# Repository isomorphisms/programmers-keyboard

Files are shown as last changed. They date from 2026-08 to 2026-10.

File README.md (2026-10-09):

# Programmer’s Keyboard

A modular keyboard project built around dedicated keypads for programming, mathematics, navigation, and command-heavy work.

The repository contains generated keypad layouts and the first routed hardware segment. It is experimental hardware, not a finished keyboard product.

## Key groups

- cursor and page movement
- process and system signals
- mathematical symbols such as `÷`, `≤`, `×`, `=`, `−`, and `⇒`
- programming symbols and operations
- regular-expression anchors and quantifiers
- concept separation and naming
- command-history search and completion
- several visible paste buffers

Layout previews are in [`pictures of the keypads`](pictures%20of%20the%20keypads). [`render-keypads`](render-keypads) generates them from ordinary Idris 2: Idris writes SVG layouts, then standard Debian tools produce PNG previews and raw PGM copies.

## Movement keypad prototype

The first routed segment is a 132 mm × 70 mm USB-C/RP2040 board with:

- twelve hot-swap key positions
- twelve diodes
- a 3×4 key matrix
- four mounting holes

Files:

- [Gerber ZIP](fabrication/movement-prototype-gerbers.zip)
- [Gerber, drill, BOM, and placement files](fabrication/movement-prototype-gerbers)
- [PCB preview](fabrication/movement-prototype-pcb.svg)
- [schematic preview](fabrication/movement-prototype-schematic.svg)
- [readable netlist](fabrication/movement-prototype-readable.netlist)
- [tscircuit source](pcb/movement-prototype.tsx)
- [source and validation notes](pcb)

Routed Movement keypad prototype

## Status

This board is a routing prototype. It has not been declared ready to order. Switch mechanics, USB protection, enclosure clearances, firmware, component availability, and final electrical review remain open.

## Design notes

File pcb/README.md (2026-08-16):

# Movement keypad PCB prototype

This is the first deliberately small electrical segment of the programmers' keyboard. It is not the complete keyboard.

The board contains:

- one complete RP2040 support circuit;
- one USB-C connector for USB data and power;
- twelve Kailh-style hot-swap key positions;
- twelve matrix diodes;
- a 3-row by 4-column key matrix; and
- four non-plated mounting holes.

The key faces use semantic operations rather than Vim letters:

| Row | Keys |
| --- | --- |
| 1 | Movement, Type, Previous Line, Next Line |
| 2 | Start Line, End Line, Next Word, Next Space-Separated Word |
| 3 | 7 Times, 13 Times, Delete Character, Delete Word |

The controller maps GPIO0–GPIO2 to the rows and GPIO3–GPIO6 to the columns. The rectangular board is 132 mm by 70 mm. Placement is explicit; tscircuit's local autorouter handles the copper.

## Generate the fabrication package

From this directory:

```sh
npm ci
npm run typecheck
npx tsci export movement-prototype.tsx --format circuit-json \
  --output ../fabrication/movement-prototype.circuit.json
npx tsci export movement-prototype.tsx --format pcb-svg \
  --output ../fabrication/movement-prototype-pcb.svg
npx tsci export movement-prototype.tsx --format schematic-svg \
  --output ../fabrication/movement-prototype-schematic.svg
npx tsci export movement-prototype.tsx --format readable-netlist \
  --output ../fabrication/movement-prototype-readable.netlist
npx tsci export movement-prototype.tsx --format gerbers \
  --output ../fabrication/movement-prototype-gerbers.zip
```

Extract the ZIP before validating:

```sh
rm -rf ../fabrication/movement-prototype-gerbers
mkdir -p ../fabrication/movement-prototype-gerbers
unzip -q ../fabrication/movement-prototype-gerbers.zip \
  -d ../fabrication/movement-prototype-gerbers
node scripts/validate-output.mjs
```

The GitHub workflow repeats this process and checks that the committed Gerber layers, drills, previews, netlist, and Circuit JSON reproduce from the source. The validator rejects circuit error elements, missing keys or diodes, missing RP2040/USB-C parts, too few routed traces, missing Gerber layers, and missing or implausibly small drill files.

The currently checked-in run reports 63 components, 146 source traces, 125 routed PCB traces, 10 Gerber layers, and 2 drill files.

This is a routing prototype, not yet a production release. Switch choice, key spacing, board outline, ESD protection, firmware, component availability, and mechanical enclosure still need human review before ordering boards.

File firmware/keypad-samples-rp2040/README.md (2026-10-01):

# RP2040 samples for the remaining keypad layouts

This directory extends the existing RP2040/TinyUSB pattern without claiming that the remaining keypad PCBs have been routed. It builds one UF2 per currently unimplemented layout:

- Concept Separation
- Incantation Assistance
- Math
- Regular Expressions
- Several Pastebins
- Signals

The routed Movement board remains in `firmware/movement-rp2040`. The Programming `λ` proof remains on the separate `firmware/programming-lambda` branch; this directory does not replace either of them.

## Hardware assumption for these samples

The remaining layouts do not yet have checked-in PCB wiring, and the current Regex meaning list needs thirteen distinct actions. The sample therefore assumes one common diode-isolated 4×4 switch matrix:

- rows: GPIO0, GPIO1, GPIO2, GPIO3
- columns: GPIO4, GPIO5, GPIO6, GPIO7
- columns use RP2040 internal pull-ups
- one row at a time is driven low; inactive rows float
- each switch is wired from its column to the diode anode, with the diode cathode connected to its row, matching the routed Movement matrix direction
- a closed switch reads low on its column
- five consecutive 1 ms samples are required before a state change is accepted

This is **not** the routed Movement prototype pinout. Movement is 3×4 with rows GPIO0–GPIO2 and columns GPIO3–GPIO6. These UF2s are samples for breadboarding or later PCB work; do not flash one onto the Movement board and assume its physical key positions match.

All tables below use row-major matrix positions: position 0 is row 0/column 0, position 1 is row 0/column 1, position 4 is row 1/column 0, and so on. Unlisted positions do nothing. Where `Renderer.idr` already defines rows, the sample leaves unused column 3 positions empty so those rows remain recognizable inside the common 4×4 matrix.

## Concept Separation

The existing rendered rows are 4 + 2, which fit directly in the common matrix.

| Position | Current meaning | Sample host encoding |
| ---: | --- | --- |
| 0 | QUAD SPACE | U+2001 EM QUAD via Linux `Ctrl+Shift+U 2001 Enter` |
| 1 | FOUR SPACES | four ASCII spaces |
| 2 | DOUBLE SPACE | two ASCII spaces |
| 3 | SINGLE SPACE | one ASCII space |
| 4 | INDENT | `Tab` |
| 5 | UNDERSCORE | `_` |

`QUAD SPACE` is kept as a distinct semantic action from `FOUR SPACES`; this sample interprets the former as the Unicode EM QUAD rather than silently making the two keys identical.

## Incantation Assistance

The existing rendered layout is one row of three keys.

| Position | Current meaning | HID output |
| ---: | --- | --- |
| 0 | TAB / COMPLETE | `Tab` |
| 1 | FINISH INCANTATION | `Enter` |
| 2 | CHANT HISTORY | `Ctrl-R` |

## Math

The rendered Math layout has two rows of four faces plus a third-row `⇒` face. The text source gives the two comparison faces paired meanings, `< / ≤` and `> / ≥`. To preserve both meanings without inventing a tap/hold convention, the sample assumes each of those two faces is a two-contact rocker. The extra contacts occupy otherwise-unused matrix positions 10 and 11; their matrix coordinates are wiring choices, not extra visible key faces.

For a concrete SPDT implementation, the `< / ≤` rocker can put its common on column 2, with one throw going through a diode to row 1 (position 6) and the other through a diode to row 2 (position 10). The `> / ≥` rocker can do the same on column 3 for positions 7 and 11. Two electrically independent normally-open contacts are equivalent. In either case the diode anode is on the contact/column side and the cathode is on the row side.

Unicode operators use the same Linux Unicode-input approach as the existing Programming `λ` proof.

| Position | Current meaning | Sample host encoding |
| ---: | --- | --- |
| 0 | ADD | `+` |
| 1 | SUBTRACT | U+2212 `−` |
| 2 | MULTIPLY | U+00D7 `×` |
| 3 | DIVIDE | U+00F7 `÷` |
| 4 | EQUAL | `=` |
| 5 | NOT EQUAL | U+2260 `≠` |
| 6 | `<` contact of `< / ≤` | `<` |
| 10 | `≤` contact of `< / ≤` | U+2264 `≤` |
| 7 | `>` contact of `> / ≥` | `>` |
| 8 | FAT ARROW | U+21D2 `⇒` |
| 11 | `≥` contact of `> / ≥` | U+2265 `≥` |

A final PCB can choose different matrix coordinates for the second rocker contacts without changing the semantic actions or encodings.

## Regular Expressions

The text definition, `Renderer.idr`, and the firmware now use the same thirteen meanings in the same row-major 4 + 4 + 4 + 1 arrangement. The firmware build checks that agreement before compiling the UF2, so changing any one of those three representations without updating the others fails CI.

This encoder targets PCRE2/Perl-like syntax on a US keyboard layout. The semantic names stay separate from that dialect choice.

| Position | Current meaning | Sample text |
| ---: | --- | --- |
| 0 | START OF LINE | `^` |
| 1 | END OF LINE | `$` |
| 2 | END OF SLURP | `\z` |
| 3 | maybe (ok if not?) | `?` |
| 4 | big capture (greedy) | `(.*)` |
| 5 | small capture (non greedy) | `(.*?)` |
| 6 | group of characters in exactly this order | `()` |
| 7 | any character from this list | `[]` |
| 8 | letter | `\p{L}` |
| 9 | number | `\d` |
| 10 | non weird character | `\w` |
| 11 | weird character | `\W` |
| 12 | incantation runes / control characters | `\p{Cc}` |

If another regex dialect is desired, change only these text encodings; the semantic names do not need to change.

## Several Pastebins

The existing rendered layout is 3×3. Column 3 of each sample matrix row is therefore unused.

The repository defines pastebin operations but not a universal host shortcut or daemon. Guessing clipboard shortcuts would change the meaning. The sample therefore emits otherwise-unused extended function-key usages for a host binding layer:

| Position | Current meaning | HID transport token |
| ---: | --- | --- |
| 0 | VIEW₁ | `F13` |
| 1 | VIEW₂ | `F14` |
| 2 | VIEW₃ | `F15` |
| 4 | REMEMBER₁ | `F16` |
| 5 | REMEMBER₂ | `F17` |
| 6 | REMEMBER₃ | `F18` |
| 8 | WRITE₁ | `F19` |
| 9 | WRITE₂ | `F20` |
| 10 | WRITE₃ | `F21` |

A host binding can then implement the actual three pastebins without changing firmware key identity.

## Signals

The existing rendered layout is two rows of three keys, so the second row begins at matrix position 4.

A USB keyboard cannot itself select an arbitrary process and call `kill(2)`. These samples therefore preserve each signal as a distinct HID transport token rather than pretending an ordinary keystroke universally means SIGTERM or SIGKILL.

| Position | Current meaning | Firmware behavior |
| ---: | --- | --- |
| 0 | QUIT PROGRAM — SIGINT | `F13` token |
| 1 | SLEEP PROGRAM — SIGTSTP | `F14` token |
| 2 | WAKE PROGRAM — SIGCONT | `F15` token |
| 4 | SHUTDOWN — SIGTERM `[hold]` | after 1 s hold, `F16` token |
| 5 | QUIT AND DUMP — SIGQUIT | `F17` token |
| 6 | KILL PROGRAM — SIGKILL `[guarded]` | after 2 s hold, `F18` token |

The final SIGKILL key is still expected to have a physical guard/cover. The 2 s software hold is additional sample protection, not a replacement for that hardware assumption. Host software must bind the tokens to the intended process and exact signals.

Because the Pastebins and Signals samples reuse some F13–F18 transport usages, host software that binds those tokens must distinguish the originating USB device rather than treating them as global keyboard shortcuts.

## Build all six UF2 files

Use Raspberry Pi Pico SDK 2.2.0 and an Arm embedded GCC toolchain:

```sh
export PICO_SDK_PATH=/path/to/pico-sdk
cmake -S firmware/keypad-samples-rp2040 -B build/keypad-samples-rp2040
cmake --build build/keypad-samples-rp2040 --parallel
```

Outputs:

```text
build/keypad-samples-rp2040/concept_separation_keypad.uf2
build/keypad-samples-rp2040/incantation_keypad.uf2
build/keypad-samples-rp2040/math_keypad.uf2
build/keypad-samples-rp2040/regex_keypad.uf2
build/keypad-samples-rp2040/pastebins_keypad.uf2
build/keypad-samples-rp2040/signals_keypad.uf2
```

The GitHub Actions workflow uploads those six files together as `keypad-samples-rp2040-uf2`.

## Prototype USB identities

The existing Programming `λ` proof already uses prototype identity `CAFE:4005`, so these samples use distinct prototype PIDs and product strings:

| Layout | Prototype VID:PID |
| --- | --- |
| Concept Separation | `CAFE:4010` |
| Incantation Assistance | `CAFE:4011` |
| Math | `CAFE:4012` |
| Regular Expressions | `CAFE:4013` |
| Several Pastebins | `CAFE:4014` |
| Signals | `CAFE:4015` |

These are development identities, not an allocated product VID/PID range. Allocate a proper USB identity before distributing a product.

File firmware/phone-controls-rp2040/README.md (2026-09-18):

# RP2040 phone call controls

This is an experiment for physical phone controls that travel through the normal
USB HID -> Linux input -> Android input path.  It deliberately does **not** use
F-keys as stand-ins for phone actions.

## The useful stock-Android path

Button 0 emits USB HID Consumer usage `0x00cd` (`Play/Pause`).  The generic
Linux HID input driver maps that usage to `KEY_PLAYPAUSE`; Android's generic key
layout maps that Linux key to `MEDIA_PLAY_PAUSE` / `KEYCODE_MEDIA_PLAY_PAUSE`.
Android documents the same usage for headset call control:

- incoming call + short press -> answer
- incoming call + long press -> reject
- ongoing call + short press -> disconnect
- ongoing call + long press -> mute or unmute microphone

The firmware keeps `0x00cd` asserted for exactly as long as the physical HOOK
button remains down, rather than synthesizing a fixed-duration tap.  That leaves
short-versus-long interpretation to Android.

This makes one physical **HOOK** button useful without an Android companion app
or an F-key remapping layer.  Device/dialer behavior still has to be tested on
the actual phone: Android's telephony compatibility document strongly
recommends the call behavior, while its USB-headset specification gives the
same `0x00cd` mapping explicitly.

## A separate CALL probe

Button 1 emits USB HID Consumer usage `0x008c` (`Media Select Telephone`).  The
generic Linux HID input driver maps it to `KEY_PHONE` and AOSP's `Generic.kl`
maps Linux key 169 to Android `CALL` / `KEYCODE_CALL`.

This is intentionally called a **probe**.  `CALL` is a real Android key, but the
action it produces depends on telephony and dialer state.  Testing it on the
actual phone tells us whether it is useful as a separate ANSWER/CALL control.

## Why there is no fake END CALL button

Android defines `KEYCODE_ENDCALL`, but current AOSP `Generic.kl` does not map a
generic external Linux input key to `ENDCALL`.  Newer Linux headers have
`KEY_HANGUP_PHONE`, but AOSP's generic external-keyboard map does not give that
key `ENDCALL` semantics.  The generic Linux HID telephony-page handling also
does not currently turn the HID telephony Hook Switch / Drop usages into a
portable answer-only and hang-up-only pair.

So two firmware buttons labelled ANSWER and HANG UP cannot honestly be made
independent merely by assigning two arbitrary HID/F-key codes.  A dedicated
hang-up-only button needs one of these additional boundaries:

- a phone-specific Android key-layout mapping,
- an Android-side service with permission to act on call state,
- a custom/system Android build,
- or a two-way accessory protocol in which the phone tells the keyboard the
  current call state.

Until one of those exists, the state-dependent HOOK button is the clean
firmware-only control.

## Wiring

Both buttons are active-low and use RP2040 internal pull-ups:

| GPIO | label | USB Consumer usage | intended experiment |
| ---: | --- | ---: | --- |
| 2 | HOOK | `0x00cd` | answer/reject ringing; hang up/mute active call |
| 3 | CALL probe | `0x008c` | observe Android `CALL` behavior |

Each switch simply connects its GPIO pin to GND when pressed.  If both buttons
are held at once, HOOK has priority.

## Build

```sh
export PICO_SDK_PATH=/path/to/pico-sdk
cmake -S firmware/phone-controls-rp2040 -B build/phone-controls-rp2040
cmake --build build/phone-controls-rp2040 --parallel
```

The flashable output is `build/phone-controls-rp2040/phone_controls.uf2`.

## What to verify on hardware

The useful acceptance cases are behavioral, not merely "Android saw a USB
keyboard":

1. idle phone + HOOK: must not unexpectedly place a call;
2. incoming call + HOOK short press: answers;
3. incoming call + HOOK long press: rejects;
4. active call + HOOK short press: disconnects;
5. active call + HOOK long press: mutes/unmutes;
6. incoming/active/idle states + CALL probe: record exactly what the phone does;
7. remove the accessory and confirm ordinary phone behavior is unchanged.

If Linux input tracing is available during bench testing, the expected events
are `KEY_PLAYPAUSE` for HOOK and `KEY_PHONE` for CALL probe.

## Sources that define the boundary

- AOSP generic external-keyboard map:
  https://android.googlesource.com/platform/frameworks/base/+/refs/heads/main/data/keyboards/Generic.kl
- Android `KeyEvent` key-code definitions:
  https://android.googlesource.com/platform/frameworks/base/+/refs/heads/main/core/java/android/view/KeyEvent.java
- Linux generic HID input mapping:
  https://github.com/torvalds/linux/blob/master/drivers/hid/hid-input.c
- Linux input key definitions:
  https://github.com/torvalds/linux/blob/master/include/uapi/linux/input-event-codes.h
- Android compatibility requirements:
  https://source.android.com/docs/compatibility/cdd
- Android USB-headset HID mapping:
  https://source.android.com/docs/core/interaction/accessories/headset/usb-device

## Separate hardware problem: keeping the USB-C port usable

This firmware only defines the accessory's input behavior.  Simultaneous USB
host operation and charging/pass-through is a USB-C hub / role / power-delivery
hardware problem.  It must not be represented as something the key firmware
solves.

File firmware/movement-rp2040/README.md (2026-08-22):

# RP2040 Movement keypad firmware

This is the first firmware for the checked-in Movement keypad Gerbers. It targets the RP2040 already on that board and scans the existing 3×4 switch matrix:

- rows: GPIO0, GPIO1, GPIO2
- columns: GPIO3, GPIO4, GPIO5, GPIO6

The columns use the RP2040's internal pull-ups. One row at a time is driven low; the other rows float. The switch diodes on the PCB therefore make a pressed key read low on its column. Five consecutive 1 ms samples are required before a state change is accepted.

## What the twelve keys send

The first board is the Vim-oriented movement segment, so the semantic keys become ordinary USB HID keyboard reports:

| Key face | HID output |
| --- | --- |
| Movement | `Esc` |
| Type | `i` |
| Previous Line | `k` |
| Next Line | `j` |
| Start Line | `0` |
| End Line | `$` (`Shift+4`) |
| Next Word | `w` |
| Next Space-Separated Word | `W` (`Shift+w`) |
| 7 Times | `7` |
| 13 Times | `13` |
| Delete Character | `x` |
| Delete Word | `dw` |

Multi-character operations are emitted as press/release sequences, so `13` and `dw` are real key sequences rather than invented HID codes.

## Build a UF2

Install a recent Raspberry Pi Pico SDK and the Arm embedded GCC toolchain, then point `PICO_SDK_PATH` at the SDK checkout.

```sh
cd firmware/movement-rp2040
mkdir -p build
cd build
cmake ..
cmake --build . -j
```

The flashable file is:

```text
build/movement_keypad.uf2
```

The repository workflow also builds this UF2 and uploads it as the `movement-keypad-uf2` Actions artifact, so a local cross-compiler is not required just to obtain the firmware image.

## Flash it over the board's USB-C connector

A separate PIC programmer is not needed for this board. The checked-in RP2040 support circuit already has `SW_BOOT` and `SW_RUN` plus SWD test points.

1. Connect the board to a computer with a USB-C data cable.
2. Hold `SW_BOOT`.
3. Tap `SW_RUN`, then release `SW_BOOT`.
4. The RP2040 ROM should enumerate as the `RPI-RP2` USB mass-storage device.
5. Copy `movement_keypad.uf2` onto that drive. The board reboots into the firmware automatically.

If USB boot is ever unavailable, the `SWDIO`, `SWCLK`, `3V3`, and `GND` test points provide the lower-level recovery/programming path.

## Scope

This firmware deliberately matches the existing Movement prototype rather than pretending the rest of the keyboard PCB already exists. The USB VID/PID are TinyUSB-style prototype values (`CAFE:4004`); allocate a proper VID/PID before distributing a product.

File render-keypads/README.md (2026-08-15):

# Idris2 keypad picture renderer

`src/Renderer.idr` contains the category names, semantic key labels, and sample table geometry. It uses ordinary Idris2 and does not use HTML or CSS.

From the repository root:

```sh
idris2 --build render-keypads/render-keypads.ipkg
./render-keypads/build/exec/render-keypads
bash render-keypads/convert-to-png.sh
```

The Idris2 program writes SVG because GitHub renders it directly and because text remains clear at any scale. The conversion script uses Debian's `rsvg-convert` and ImageMagick to write PNG previews and raw PGM (`P5`) files. PGM is the Netpbm greyscale format used in chapter 10 of *Real World Haskell*.

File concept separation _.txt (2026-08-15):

concept separation _
====================

QUAD SPACE
FOUR SPACES
DOUBLE SPACE
SINGLE SPACE
↹  INDENT
_  UNDERSCORE

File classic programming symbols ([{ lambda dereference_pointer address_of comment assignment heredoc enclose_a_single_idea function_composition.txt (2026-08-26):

classic programming symbols ([{ lambda dereference_pointer address_of comment assignment heredoc enclose_a_single_idea function_composition
===========================================================================================================================================

TALL LEFT DELIMITER  —  { / ( / [
TALL RIGHT DELIMITER  —  } / ) / ]
⟨ ⟩  PAIRED DELIMITER
⟦ ⟧  PAIRED EVALUATION — emit ⟦⟧, then move left once, leaving the cursor at ⟦|⟧
λ
ƒ
=def / ≝  DEFINITION
⟵  ASSIGN
→  ASSIGN
∘  COMPOSE
|>  VALUE PIPE
>>  THEN / POST-COMPOSE
&  ADDRESS
*  DEREFERENCE
*  POINTER TYPE
*  SPLAT
$  PERL SCALAR
@  PERL ARRAY
%  PERL HASH
.
:
;
'
`
"
/
\
|
#  COMMENT
“ ”  PAIRED QUOTES
« »  PAIRED QUOTES
𝔽  FLOAT
DD  DOUBLE
CC  CHAR
SS  STRING
DO
LOOP
f"""  START TEXT

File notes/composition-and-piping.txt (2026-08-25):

Composition and piping notation — working note
==============================================

Keep value piping distinct from function composition.

|>  VALUE PIPE
    A value is sent into the next operation.

>>  THEN / POST-COMPOSE
    Read left-to-right: f >> g means do f, then g.
    A keycap could put THEN above >>.

<<  BEFORE / PRE-COMPOSE CANDIDATE
    If >> is retained for post-composition, << is the natural symmetric candidate
    for the opposite direction. Do not add it as a settled key yet.

∘   ORDINARY COMPOSITION
    Keep the ring operator available for conventional mathematical composition.
    A keycap word such as BEFORE or FIRST may make its reading direction clearer,
    but that label is not settled yet.

The visual model to optimize for is ordinary left-to-right flow:

    x  --->  f  --->  g  --->  h

The notation should make that path obvious rather than force the reader to remember
which side is called left/right composition or multiplication. This matters even
more when f, g, h represent maps or homotopies attached to a loop x on a surface S.

Do not collapse |> and >> into the same operation merely because both read
left-to-right: one pipes a value; the other composes functions.

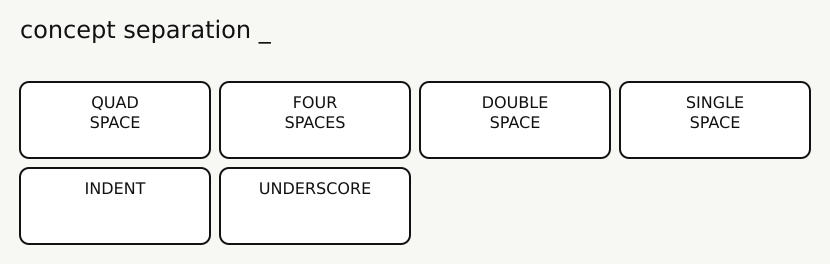
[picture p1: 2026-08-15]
pictures of the keypads/concept separation _.png

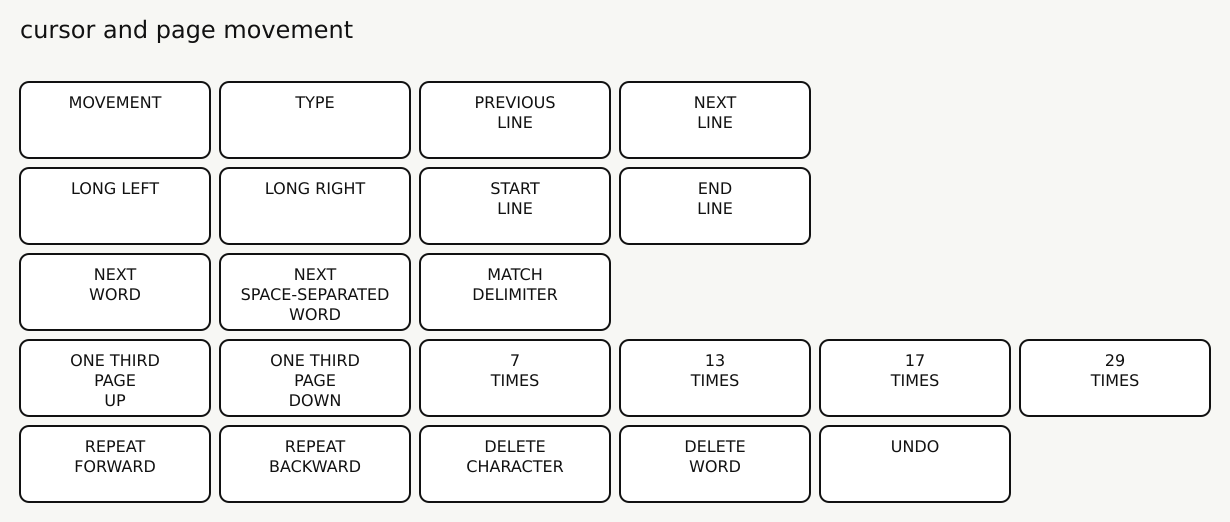
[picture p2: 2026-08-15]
pictures of the keypads/cursor and page movement.png

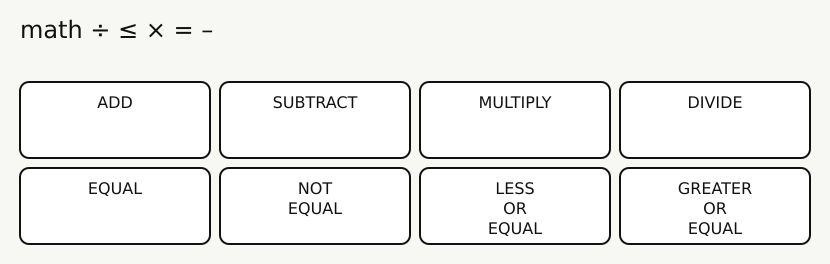
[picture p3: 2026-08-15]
pictures of the keypads/math ÷ ≤ × = –.png

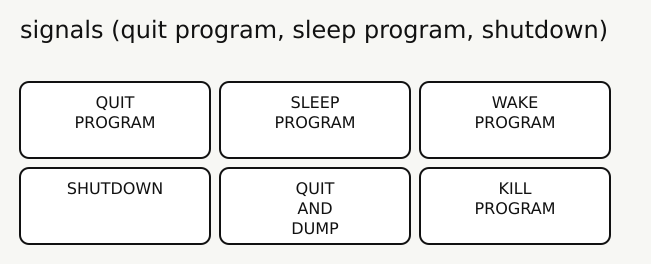
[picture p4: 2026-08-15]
pictures of the keypads/signals (quit program, sleep program, shutdown).png

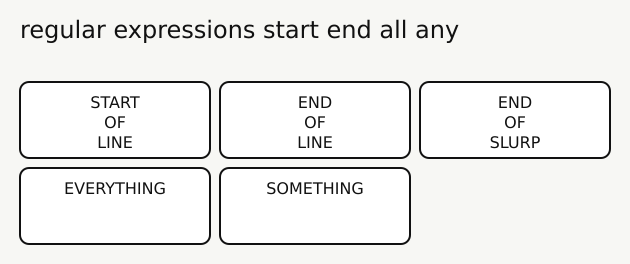
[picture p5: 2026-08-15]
pictures of the keypads/regular expressions start end all any.png

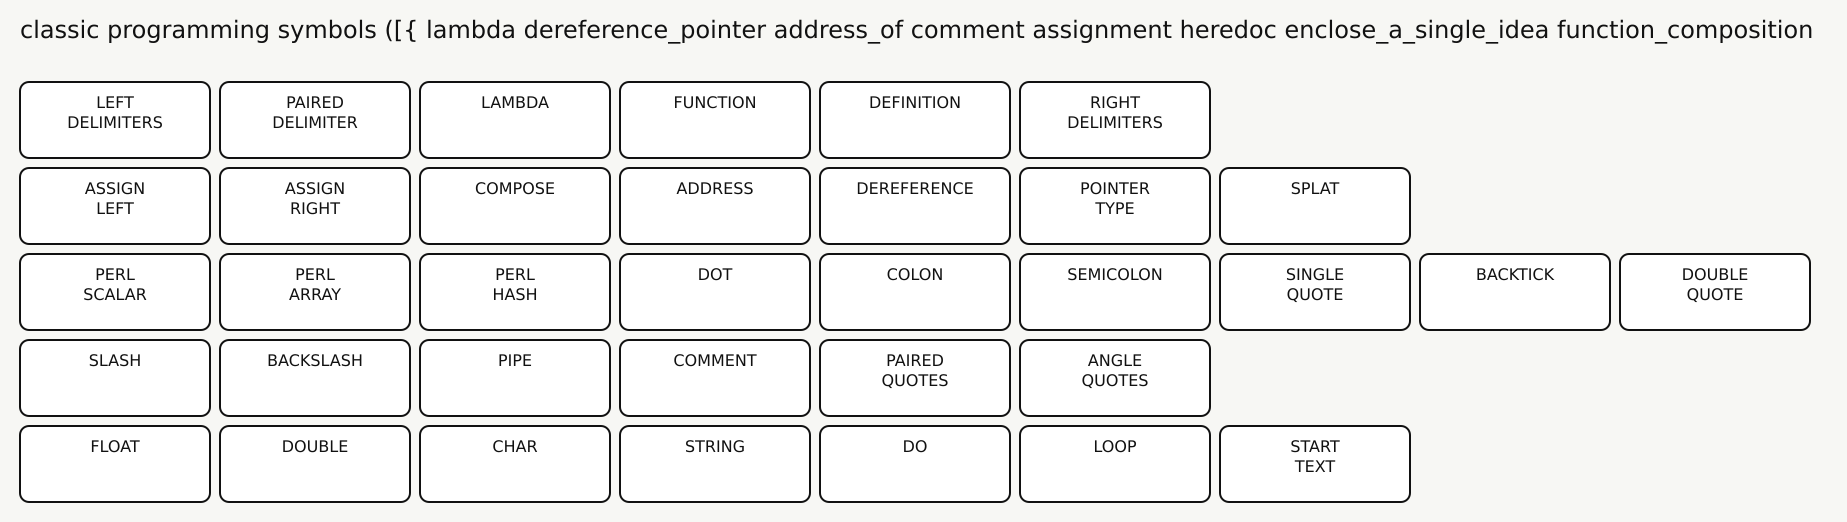
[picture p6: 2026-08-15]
pictures of the keypads/classic programming symbols ([{ lambda dereference_pointer address_of comment assignment heredoc enclose_a_single_idea function_composition.png

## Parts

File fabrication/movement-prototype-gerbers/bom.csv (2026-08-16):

Designator | Comment | Value | Footprint | JLCPCB Part #
D_VBUS |  |  |  | C8598
R_3V3_EN | 100k | 100k |  | C25741
C_IOVDD1 | 100n | 100n |  | C1525
C_IOVDD2 | 100n | 100n |  | C1525
C_IOVDD3 | 100n | 100n |  | C1525
C_IOVDD4 | 100n | 100n |  | C1525
C_IOVDD5 | 100n | 100n |  | C1525
C_IOVDD6 | 100n | 100n |  | C1525
R_RUN | 10k | 10k |  | C25744
C_FLASH | 100n | 100n |  | C1525
C_USB_VDD | 100n | 100n |  | C1525
C_ADC | 100n | 100n |  | C1525
J_USB |  |  |  | C2765186
U1 |  |  |  | C2040
U2 |  |  |  | C2843335
U3 |  |  |  | C23380830
Y1 |  |  |  | C9002
SW_BOOT |  |  |  | C139797
SW_RUN |  |  |  | C139797
D1 |  |  |  | C965799
D_PWR |  |  |  | C965799
R_BOOT | 10k | 10k |  | C25744
R_LED | 330 | 330 |  | C25104
R_PWR_LED | 330 | 330 |  | C25104
R_CC1 | 5.1k | 5.1k |  | C25905
R_CC2 | 5.1k | 5.1k |  | C25905
R_USB1 | 27 | 27 |  | C25100
R_USB2 | 27 | 27 |  | C25100
C_VBUS | 10µ | 10µ |  | C19702
C_3V3 | 10µ | 10µ |  | C19702
C_CORE | 1µ | 1µ |  | C52923
C_USB | 1µ | 1µ |  | C52923
C_XIN | 18p | 18p |  | C1549
C_XOUT | 18p | 18p |  | C1549
L_AVDD |  |  |  | C1002
TP_SWCLK
TP_GND
TP_SWDIO
TP_3V3
K1
D1
K2
D2
K3
D3
K4
D4
K5
D5
K6
D6
K7
D7
K8
D8
K9
D9
K10
D10
K11
D11
K12
D12

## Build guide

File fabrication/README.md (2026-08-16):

# Movement prototype fabrication package

The immediately downloadable board package is [`movement-prototype-gerbers.zip`](movement-prototype-gerbers.zip). Its contents are also extracted into [`movement-prototype-gerbers`](movement-prototype-gerbers) so they can be inspected individually on GitHub.

## Contents

- front and back copper;
- front and back solder mask;
- front and back paste;
- front and back silkscreen;
- fabrication and edge-cut layers;
- plated and non-plated Excellon drill files;
- bill of materials;
- pick-and-place data;
- routed PCB and schematic SVG previews;
- readable netlist; and
- full Circuit JSON.

The successful generation run validated 63 source components, 146 source traces, 125 routed PCB traces, 10 Gerber layers, and 2 drill files without circuit error elements.

This is the first Movement-keypad routing prototype. It has not yet received a human production review and should not be sent straight to a board house without checking the electrical design, footprints, mechanics, clearances, and parts list.

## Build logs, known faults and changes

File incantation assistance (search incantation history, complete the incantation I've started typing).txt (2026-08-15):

incantation assistance (search incantation history, complete the incantation I've started typing)
=================================================================================================

TAB / COMPLETE
FINISH INCANTATION
CHANT HISTORY  —  Ctrl-R

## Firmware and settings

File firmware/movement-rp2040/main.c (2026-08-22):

#include <stdbool.h>
#include <stdint.h>

#include "bsp/board_api.h"
#include "hardware/gpio.h"
#include "pico/stdlib.h"
#include "tusb.h"

#define ROW_COUNT 3u
#define COL_COUNT 4u
#define KEY_COUNT (ROW_COUNT * COL_COUNT)
#define DEBOUNCE_SCANS 5u
#define EVENT_QUEUE_SIZE 16u

static const uint row_pins[ROW_COUNT] = {0u, 1u, 2u};
static const uint col_pins[COL_COUNT] = {3u, 4u, 5u, 6u};

typedef struct {
    uint8_t modifier;
    uint8_t keycode;
} chord_t;

typedef struct {
    const chord_t *chords;
    uint8_t count;
} macro_t;

static const chord_t macro_movement[] = {{0, HID_KEY_ESCAPE}};
static const chord_t macro_type[] = {{0, HID_KEY_I}};
static const chord_t macro_prev_line[] = {{0, HID_KEY_K}};
static const chord_t macro_next_line[] = {{0, HID_KEY_J}};
static const chord_t macro_start_line[] = {{0, HID_KEY_0}};
static const chord_t macro_end_line[] = {{KEYBOARD_MODIFIER_LEFTSHIFT, HID_KEY_4}};
static const chord_t macro_next_word[] = {{0, HID_KEY_W}};
static const chord_t macro_next_space_word[] = {{KEYBOARD_MODIFIER_LEFTSHIFT, HID_KEY_W}};
static const chord_t macro_7_times[] = {{0, HID_KEY_7}};
static const chord_t macro_13_times[] = {{0, HID_KEY_1}, {0, HID_KEY_3}};
static const chord_t macro_delete_char[] = {{0, HID_KEY_X}};
static const chord_t macro_delete_word[] = {{0, HID_KEY_D}, {0, HID_KEY_W}};

static const macro_t keymap[KEY_COUNT] = {
    {macro_movement, 1},
    {macro_type, 1},
    {macro_prev_line, 1},
    {macro_next_line, 1},
    {macro_start_line, 1},
    {macro_end_line, 1},
    {macro_next_word, 1},
    {macro_next_space_word, 1},
    {macro_7_times, 1},
    {macro_13_times, 2},
    {macro_delete_char, 1},
    {macro_delete_word, 2},
};

static uint8_t event_queue[EVENT_QUEUE_SIZE];
static uint8_t event_head;
static uint8_t event_tail;

static bool raw_previous[KEY_COUNT];
static bool debounced[KEY_COUNT];
static uint8_t debounce_count[KEY_COUNT];

static int8_t active_macro = -1;
static uint8_t active_chord;
static bool release_pending;

static bool queue_empty(void) {
    return event_head == event_tail;
}

static bool queue_full(void) {
    return (uint8_t)((event_head + 1u) % EVENT_QUEUE_SIZE) == event_tail;
}

static void queue_keypress(uint8_t key_index) {
    if (queue_full()) {
        return;
    }

    event_queue[event_head] = key_index;
    event_head = (uint8_t)((event_head + 1u) % EVENT_QUEUE_SIZE);
}

static uint8_t queue_pop(void) {
    uint8_t key_index = event_queue[event_tail];
    event_tail = (uint8_t)((event_tail + 1u) % EVENT_QUEUE_SIZE);
    return key_index;
}

static void matrix_init(void) {
    for (uint row = 0; row < ROW_COUNT; ++row) {
        gpio_init(row_pins[row]);
        gpio_set_dir(row_pins[row], GPIO_IN);
        gpio_disable_pulls(row_pins[row]);
    }

    for (uint col = 0; col < COL_COUNT; ++col) {
        gpio_init(col_pins[col]);
        gpio_set_dir(col_pins[col], GPIO_IN);
        gpio_pull_up(col_pins[col]);
    }
}

static void debounce_sample(uint8_t key_index, bool pressed) {
    if (pressed != raw_previous[key_index]) {
        raw_previous[key_index] = pressed;
        debounce_count[key_index] = 1;
    } else if (debounce_count[key_index] < DEBOUNCE_SCANS) {
        ++debounce_count[key_index];
    }

    if (debounce_count[key_index] < DEBOUNCE_SCANS ||
        debounced[key_index] == pressed) {
        return;
    }

    debounced[key_index] = pressed;
    if (pressed) {
        queue_keypress(key_index);
    }
}

static void matrix_scan(void) {
    for (uint row = 0; row < ROW_COUNT; ++row) {
        gpio_put(row_pins[row], 0);
        gpio_set_dir(row_pins[row], GPIO_OUT);
        busy_wait_us_32(2);

        for (uint col = 0; col < COL_COUNT; ++col) {
            uint8_t key_index = (uint8_t)(row * COL_COUNT + col);
            debounce_sample(key_index, !gpio_get(col_pins[col]));
        }

        gpio_set_dir(row_pins[row], GPIO_IN);
    }
}

static void matrix_task(void) {
    static uint64_t next_scan_us;
    uint64_t now = time_us_64();

    if (now < next_scan_us) {
        return;
    }

    next_scan_us = now + 1000u;
    matrix_scan();
}

static void hid_task(void) {
    if (!tud_hid_ready()) {
        return;
    }

    if (active_macro < 0) {
        if (queue_empty()) {
            return;
        }

        active_macro = (int8_t)queue_pop();
        active_chord = 0;
        release_pending = false;
    }

    const macro_t *macro = &keymap[(uint8_t)active_macro];

    if (!release_pending) {
        uint8_t keycodes[6] = {0};
        const chord_t *chord = &macro->chords[active_chord];
        keycodes[0] = chord->keycode;

        if (tud_hid_keyboard_report(0, chord->modifier, keycodes)) {
            release_pending = true;
        }
        return;
    }

    if (!tud_hid_keyboard_report(0, 0, NULL)) {
        return;
    }

    release_pending = false;
    ++active_chord;
    if (active_chord >= macro->count) {
        active_macro = -1;
    }
}

int main(void) {
    board_init();
    matrix_init();

    tusb_rhport_init_t dev_init = {
        .role = TUSB_ROLE_DEVICE,
        .speed = TUSB_SPEED_AUTO,
    };
    tusb_init(BOARD_TUD_RHPORT, &dev_init);
    board_init_after_tusb();

    while (true) {
        tud_task();
        matrix_task();
        hid_task();
    }
}

uint16_t tud_hid_get_report_cb(uint8_t instance,
                               uint8_t report_id,
                               hid_report_type_t report_type,
                               uint8_t *buffer,
                               uint16_t reqlen) {
    (void)instance;
    (void)report_id;
    (void)report_type;
    (void)buffer;
    (void)reqlen;
    return 0;
}

void tud_hid_set_report_cb(uint8_t instance,
                           uint8_t report_id,
                           hid_report_type_t report_type,
                           const uint8_t *buffer,
                           uint16_t bufsize) {
    (void)instance;
    (void)report_id;
    (void)report_type;
    (void)buffer;
    (void)bufsize;
}

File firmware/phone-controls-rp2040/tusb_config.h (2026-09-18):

#ifndef PROGRAMMERS_KEYBOARD_PHONE_CONTROLS_TUSB_CONFIG_H
#define PROGRAMMERS_KEYBOARD_PHONE_CONTROLS_TUSB_CONFIG_H

#ifndef BOARD_TUD_RHPORT
#define BOARD_TUD_RHPORT 0
#endif

#ifndef BOARD_TUD_MAX_SPEED
#define BOARD_TUD_MAX_SPEED OPT_MODE_DEFAULT_SPEED
#endif

#ifndef CFG_TUSB_MCU
#error CFG_TUSB_MCU must be defined by the Pico SDK
#endif

#ifndef CFG_TUSB_OS
#define CFG_TUSB_OS OPT_OS_NONE
#endif

#ifndef CFG_TUSB_DEBUG
#define CFG_TUSB_DEBUG 0
#endif

#define CFG_TUD_ENABLED 1
#define CFG_TUD_MAX_SPEED BOARD_TUD_MAX_SPEED

#ifndef CFG_TUSB_MEM_SECTION
#define CFG_TUSB_MEM_SECTION
#endif

#ifndef CFG_TUSB_MEM_ALIGN
#define CFG_TUSB_MEM_ALIGN __attribute__((aligned(4)))
#endif

#ifndef CFG_TUD_ENDPOINT0_SIZE
#define CFG_TUD_ENDPOINT0_SIZE 64
#endif

#define CFG_TUD_HID 1
#define CFG_TUD_CDC 0
#define CFG_TUD_MSC 0
#define CFG_TUD_MIDI 0
#define CFG_TUD_VENDOR 0
#define CFG_TUD_HID_EP_BUFSIZE 16

#endif

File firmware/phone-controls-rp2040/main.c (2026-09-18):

#include <stdbool.h>
#include <stddef.h>
#include <stdint.h>

#include "bsp/board_api.h"
#include "hardware/gpio.h"
#include "pico/stdlib.h"
#include "tusb.h"

#define BUTTON_COUNT 2u
#define DEBOUNCE_SCANS 5u

/*
 * USB HID Consumer usages, HID Usage Tables 1.5:
 *   0x00cd  Play/Pause
 *   0x008c  Media Select Telephone
 *
 * On the stock Linux -> Android input path:
 *   0x00cd -> KEY_PLAYPAUSE -> Android MEDIA_PLAY_PAUSE
 *   0x008c -> KEY_PHONE     -> Android CALL
 *
 * Android telephony compatibility rules give MEDIA_PLAY_PAUSE headset-hook
 * behavior.  Short press answers an incoming call and disconnects an ongoing
 * call.  Holding the physical button keeps the HID usage asserted so Android
 * can also distinguish its documented long-press actions.
 *
 * The CALL usage is kept as a separate probe because it is mapped by AOSP, but
 * its exact action is phone/dialer state dependent.
 */
#define CONSUMER_PLAY_PAUSE 0x00cdu
#define CONSUMER_MEDIA_SELECT_TELEPHONE 0x008cu

/* Active-low buttons using the RP2040's internal pull-ups. */
static const uint button_pins[BUTTON_COUNT] = {2u, 3u};
static const uint16_t button_usages[BUTTON_COUNT] = {
    CONSUMER_PLAY_PAUSE,
    CONSUMER_MEDIA_SELECT_TELEPHONE,
};

static bool raw_previous[BUTTON_COUNT];
static bool debounced[BUTTON_COUNT];
static uint8_t debounce_count[BUTTON_COUNT];

static uint16_t desired_usage;
static uint16_t reported_usage;

static void buttons_init(void) {
    for (uint8_t i = 0; i < BUTTON_COUNT; ++i) {
        gpio_init(button_pins[i]);
        gpio_set_dir(button_pins[i], GPIO_IN);
        gpio_pull_up(button_pins[i]);

        bool pressed = !gpio_get(button_pins[i]);
        raw_previous[i] = pressed;
        debounced[i] = pressed;
        debounce_count[i] = DEBOUNCE_SCANS;
    }
}

static void debounce_sample(uint8_t button_index, bool pressed) {
    if (pressed != raw_previous[button_index]) {
        raw_previous[button_index] = pressed;
        debounce_count[button_index] = 1u;
        return;
    }

    if (debounce_count[button_index] < DEBOUNCE_SCANS) {
        ++debounce_count[button_index];
    }

    if (debounce_count[button_index] >= DEBOUNCE_SCANS) {
        debounced[button_index] = pressed;
    }
}

static uint16_t current_usage(void) {
    /* HOOK has priority if both physical buttons are held simultaneously. */
    for (uint8_t i = 0; i < BUTTON_COUNT; ++i) {
        if (debounced[i]) {
            return button_usages[i];
        }
    }
    return 0u;
}

static void button_task(void) {
    static uint64_t next_scan_us;
    uint64_t now = time_us_64();

    if (now < next_scan_us) {
        return;
    }

    next_scan_us = now + 1000u;
    for (uint8_t i = 0; i < BUTTON_COUNT; ++i) {
        debounce_sample(i, !gpio_get(button_pins[i]));
    }

    desired_usage = current_usage();
}

static bool send_consumer_usage(uint16_t usage) {
    /* HID report descriptor is a single little-endian 16-bit Consumer usage. */
    uint8_t report[2] = {
        (uint8_t)(usage & 0x00ffu),
        (uint8_t)((usage >> 8) & 0x00ffu),
    };
    return tud_hid_report(0, report, sizeof(report));
}

static void hid_task(void) {
    if (desired_usage == reported_usage || !tud_hid_ready()) {
        return;
    }

    if (send_consumer_usage(desired_usage)) {
        reported_usage = desired_usage;
    }
}

int main(void) {
    board_init();
    buttons_init();

    tusb_rhport_init_t dev_init = {
        .role = TUSB_ROLE_DEVICE,
        .speed = TUSB_SPEED_AUTO,
    };
    tusb_init(BOARD_TUD_RHPORT, &dev_init);
    board_init_after_tusb();

    while (true) {
        tud_task();
        button_task();
        hid_task();
    }
}

uint16_t tud_hid_get_report_cb(uint8_t instance,
                               uint8_t report_id,
                               hid_report_type_t report_type,
                               uint8_t *buffer,
                               uint16_t reqlen) {
    (void)instance;
    (void)report_id;
    (void)report_type;
    (void)buffer;
    (void)reqlen;
    return 0;
}

void tud_hid_set_report_cb(uint8_t instance,
                           uint8_t report_id,
                           hid_report_type_t report_type,
                           const uint8_t *buffer,
                           uint16_t bufsize) {
    (void)instance;
    (void)report_id;
    (void)report_type;
    (void)buffer;
    (void)bufsize;
}

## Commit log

2026-08-16 Add routed Movement keypad fabrication package
    [B_Cu.gbr, B_Mask.gbr, B_Paste.gbr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]
2026-08-22 Use Unicode evaluation brackets
2026-08-22 Render Unicode evaluation brackets
2026-08-22 Keep Unicode bracket preview
2026-08-22 Add RP2040 firmware for Movement and remaining keypad layouts (#3)
    Land the routed Movement RP2040/TinyUSB firmware and reusable sample targets for Concept Separation, Incantation Assistance, Math, Regular Expressions, Several Pastebins, and Signals.
    Keep semantic actions separate from host encodings, verify Regex layout agreement, document the distinct 4x4 sample matrix and Movement 3x4 pinouts, and specify diode/Math-rocker wiring assumptions.
2026-08-26 Use ⟵ for left assignment
    Put ⟵ on the programming keypad as the left-assignment key, update the symbol inventory, and regenerate the SVG layout.
2026-08-30 Implement physical call-hook and CALL probe buttons
2026-10-08 Document STAR PKB-R1 baseline, sourced bookshelf and verified SUN queue
    [archive-members.tsv, audit-receipts.tsv]
2026-10-09 Compile all RP2040 firmware division sources with bare-metal ICK
    [qualification-2026-10-09.tsv]
2026-10-09 Integrate qualified RP2040 division producer into the active engineering branch
    [qualification-2026-10-09.tsv]
